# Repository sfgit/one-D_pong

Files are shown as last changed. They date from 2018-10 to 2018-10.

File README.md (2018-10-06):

# One D Pong
One dimensional pong board &amp; source code (made using Autodesk EAGLE 9.2)

This handheld version of One D pong was inspired by One D pong that a friend built for a Hackaday event ages ago.  The source code here (new) supports both one-player and two-player versions.  The files were designed in EAGLE.  To get the firmware programmed:

1)  Plug in your OTS Arduino Uno and setup as a programmer by loading the Arduino as ISP project and programming it.
2)  Next up, install a library to support programming ATMEGA 328P (there are MANY)...A few I use are:
    - https://github.com/leomil72/megax8
    - https://forum.arduino.cc/index.php?topic=412070
    
    FWIW, that second option is magical.  It uses Optiboot and is super user-friendly.  Follow the instructions on their    website and you can't go wrong.

3) Once you have that package installed, you can select the ATMEGA328 as the target and connect the Arduino's SPI (ISP) connections to the board's right-angle programming header...The pins are called out in the silkscreen on the board.
4) You'll first need to load the Arduino bootloader and you do this from the Arduino IDE using Tools->Burn Bootloader
5) With the bootloader flashed, you can then program any arduino sketch onto the board though since this is purpose-built for One-D pong, I would of course suggest using the One-D pong .ino file in this repo.

A few things to note:

- The LED driver ICs can sink more than they source.  They can only source about 10mA but they can sink something like 25mA.  This is why the LED cathodes are wired into those driver ICs and not to GND.  
- These boards were designed to be hand assembled and since I'm profoundly lazy, I chose to use Resistor Arrays and not individual resistors.  These little devices are small but they can definitely be hand soldered, probably far more easily than the TSSOP packages that the LED drivers use.  
- I made my own stencils using Kapton using the Glowforge Pro.  You can cut 5mil Dupont Kapton (non-adhesive) which you can get from Amazon using the following settings:
  - Speed: 650
  - Power: 90%
  - Passes: 3
  - Lines Per Inch: 225
  - Focus Height: 0.005in.

  This worked like a charm but took some cleanup afterwards.  The benefit of a stencil is of course repeatability.  If you have difficulty cutting Kapton, buy Mylar in 4mil sheets (again, Amazon) and cut that. 4mil Mylar will also take several passes to cut thru but I used settings very similar to the Kapton and that worked good.

Working version:

(http://www.youtube.com/watch?v=VkyKWFC-Sd0 "One Dimensional Pong")

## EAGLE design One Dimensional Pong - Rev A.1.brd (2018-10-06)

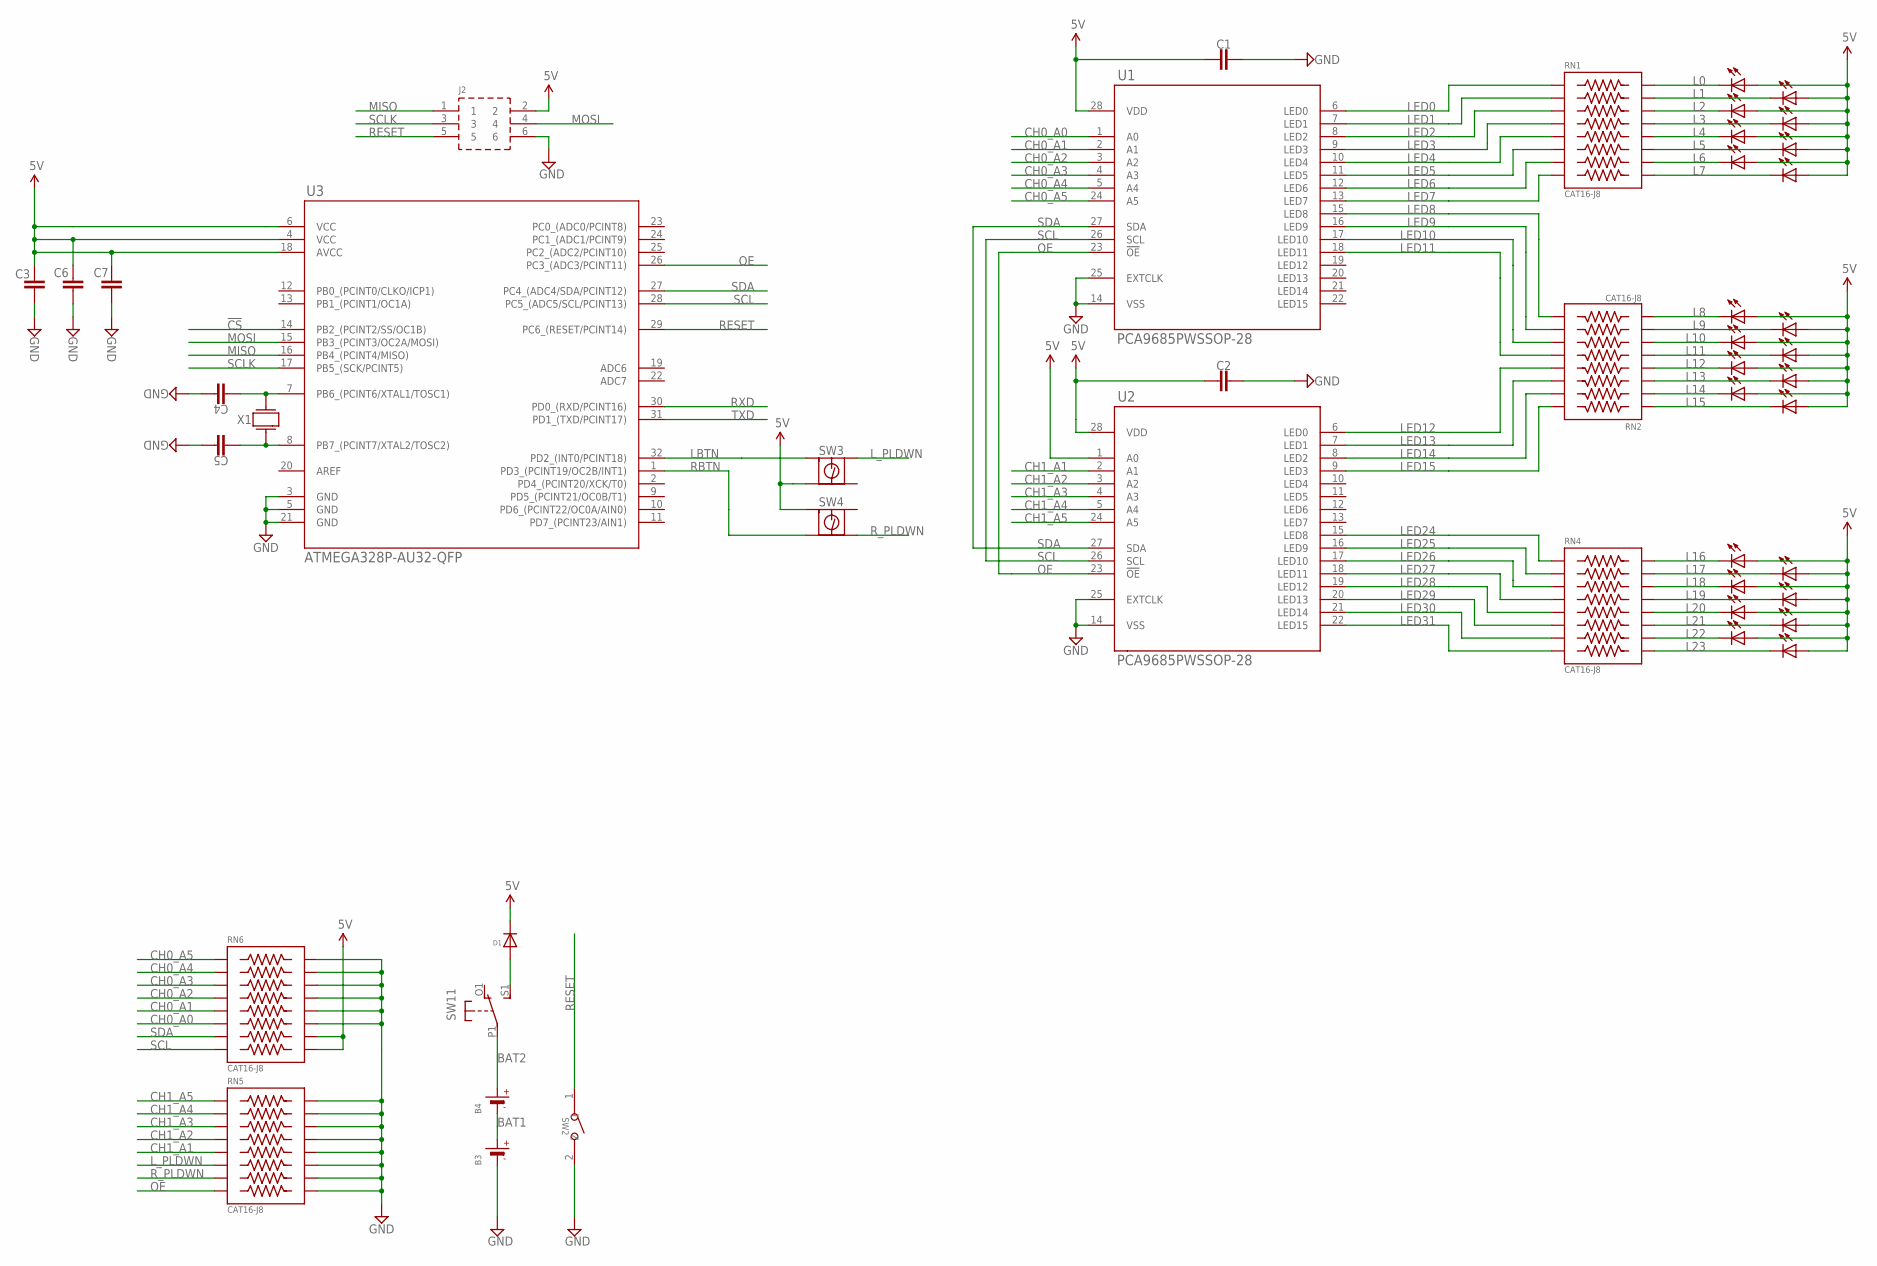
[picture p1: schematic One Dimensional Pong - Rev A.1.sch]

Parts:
B3, B4: BATTERYCR2540-SMT; CR2450
C1, C2, C3, C4, C5, C6, C7: C-EUC0805; C0805
D1: 1N4150W; SOD-123
J2: 610106249121; RA-SMT-HDR-2X3
LED1, LED5, LED28, LED32: LED0805-YELLOW; CHIP-LED0805-YELLOW
LED2, LED4, LED29, LED31: LED0805-ORANGE; CHIP-LED0805-ORANGE
LED3, LED30: LEDCHIPLED_0805; CHIPLED_0805
LED6, LED7, LED8, LED9, LED10, LED11, LED12, LED13, LED14, LED15, LED16, LED25, LED26, LED27: LED0805-GREEN; CHIP-LED0805-GREEN
RN1, RN2, RN4, RN5, RN6: CAT16-J8; RN8
SW1: DPDT-EG1390; EG1390
SW2: B3U-1000P-2P-SMD; SW2-2.6-3.0X2.5X1.2+0.4MM
SW3, SW4: PTS645SM43SMTR92LFS; PTS645-SMT-6MM
U1, U2: PCA9685PWSSOP-28; SOP65P640X110-28
U3: ATMEGA328P-AU32-QFP; QFP80P897X897X120-32
X1: ABLS-16.000MHZ-B4-T; OSC12P7X4P7

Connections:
5V: C1.1, C2.1, C3.1, C6.1, C7.1, D1.K (C), J2.2, LED1.A, LED2.A, LED3.A, LED4.A, LED5.A, LED6.A, LED7.A, LED8.A, LED9.A, LED10.A, LED11.A, LED12.A, LED13.A, LED14.A, LED15.A, LED16.A, LED25.A, LED26.A, LED27.A, LED28.A, LED29.A, LED30.A, LED31.A, LED32.A, RN6.14, RN6.16, SW3.P$3 (3), SW4.P$1 (1), U1.28 (VDD), U2.1 (A0), U2.28 (VDD), U3.4 (VCC), U3.6 (VCC), U3.18 (AVCC)
!CS: U3.14 (PB2_(PCINT2/SS/OC1B))
BAT1: B3.1 (+), B3.2 (+), B4.GND (-)
BAT2: B4.1 (+), B4.2 (+), SW1.P1
CH0_A0: RN6.11, U1.1 (A0)
CH0_A1: RN6.9, U1.2 (A1)
CH0_A2: RN6.7, U1.3 (A2)
CH0_A3: RN6.5, U1.4 (A3)
CH0_A4: RN6.3, U1.5 (A4)
CH0_A5: RN6.1, U1.24 (A5)
CH1_A1: RN5.9, U2.2 (A1)
CH1_A2: RN5.7, U2.3 (A2)
CH1_A3: RN5.5, U2.4 (A3)
CH1_A4: RN5.3, U2.5 (A4)
CH1_A5: RN5.1, U2.24 (A5)
GND: B3.GND (-), C1.2, C2.2, C3.2, C4.2, C5.2, C6.2, C7.2, J2.6, RN5.2, RN5.4, RN5.6, RN5.8, RN5.10, RN5.12, RN5.14, RN5.16, RN6.2, RN6.4, RN6.6, RN6.8, RN6.10, RN6.12, SW2.2, U1.14 (VSS), U1.25 (EXTCLK), U2.14 (VSS), U2.25 (EXTCLK), U3.3 (GND), U3.5 (GND), U3.21 (GND)
L0: LED1.C, RN1.2
L1: LED2.C, RN1.4
L2: LED3.C, RN1.6
L3: LED4.C, RN1.8
L4: LED5.C, RN1.10
L5: LED6.C, RN1.12
L6: LED7.C, RN1.14
L7: LED8.C, RN1.16
L8: LED9.C, RN2.15
L9: LED10.C, RN2.13
L10: LED11.C, RN2.11
L11: LED12.C, RN2.9
L12: LED13.C, RN2.7
L13: LED14.C, RN2.5
L14: LED15.C, RN2.3
L15: LED16.C, RN2.1
L16: LED25.C, RN4.2
L17: LED26.C, RN4.4
L18: LED27.C, RN4.6
L19: LED28.C, RN4.8
L20: LED29.C, RN4.10
L21: LED30.C, RN4.12
L22: LED31.C, RN4.14
L23: LED32.C, RN4.16
LBTN: SW3.P$1 (1), U3.32 (PD2_(INT0/PCINT18))
LED0: RN1.1, U1.6 (LED0)
LED1: RN1.3, U1.7 (LED1)
LED2: RN1.5, U1.8 (LED2)
LED3: RN1.7, U1.9 (LED3)
LED4: RN1.9, U1.10 (LED4)
LED5: RN1.11, U1.11 (LED5)
LED6: RN1.13, U1.12 (LED6)
LED7: RN1.15, U1.13 (LED7)
LED8: RN2.16, U1.15 (LED8)
LED9: RN2.14, U1.16 (LED9)
LED10: RN2.12, U1.17 (LED10)
LED11: RN2.10, U1.18 (LED11)
LED12: RN2.8, U2.6 (LED0)
LED13: RN2.6, U2.7 (LED1)
LED14: RN2.4, U2.8 (LED2)
LED15: RN2.2, U2.9 (LED3)
LED24: RN4.1, U2.15 (LED8)
LED25: RN4.3, U2.16 (LED9)
LED26: RN4.5, U2.17 (LED10)
LED27: RN4.7, U2.18 (LED11)
LED28: RN4.9, U2.19 (LED12)
LED29: RN4.11, U2.20 (LED13)
LED30: RN4.13, U2.21 (LED14)
LED31: RN4.15, U2.22 (LED15)
L_PLDWN: RN5.11, SW3.P$2 (2)
MISO: J2.1, U3.16 (PB4_(PCINT4/MISO))
MOSI: J2.4, U3.15 (PB3_(PCINT3/OC2A/MOSI))
unnamed: C4.1, U3.7 (PB6_(PCINT6/XTAL1/TOSC1)), X1.2
unnamed: C5.1, U3.8 (PB7_(PCINT7/XTAL2/TOSC2)), X1.1
unnamed: D1.A, SW1.S1 (S)
OE: RN5.15, U1.23 (!OE), U2.23 (!OE), U3.26 (PC3_(ADC3/PCINT11))
RBTN: SW4.P$3 (3), U3.1 (PD3_(PCINT19/OC2B/INT1))
RESET: J2.5, SW2.1, U3.29 (PC6_(RESET/PCINT14))
RXD: U3.30 (PD0_(RXD/PCINT16))
R_PLDWN: RN5.13, SW4.P$4 (4)
SCL: RN6.15, U1.26 (SCL), U2.26 (SCL), U3.28 (PC5_(ADC5/SCL/PCINT13))
SCLK: J2.3, U3.17 (PB5_(SCK/PCINT5))
SDA: RN6.13, U1.27 (SDA), U2.27 (SDA), U3.27 (PC4_(ADC4/SDA/PCINT12))
TXD: U3.31 (PD1_(TXD/PCINT17))

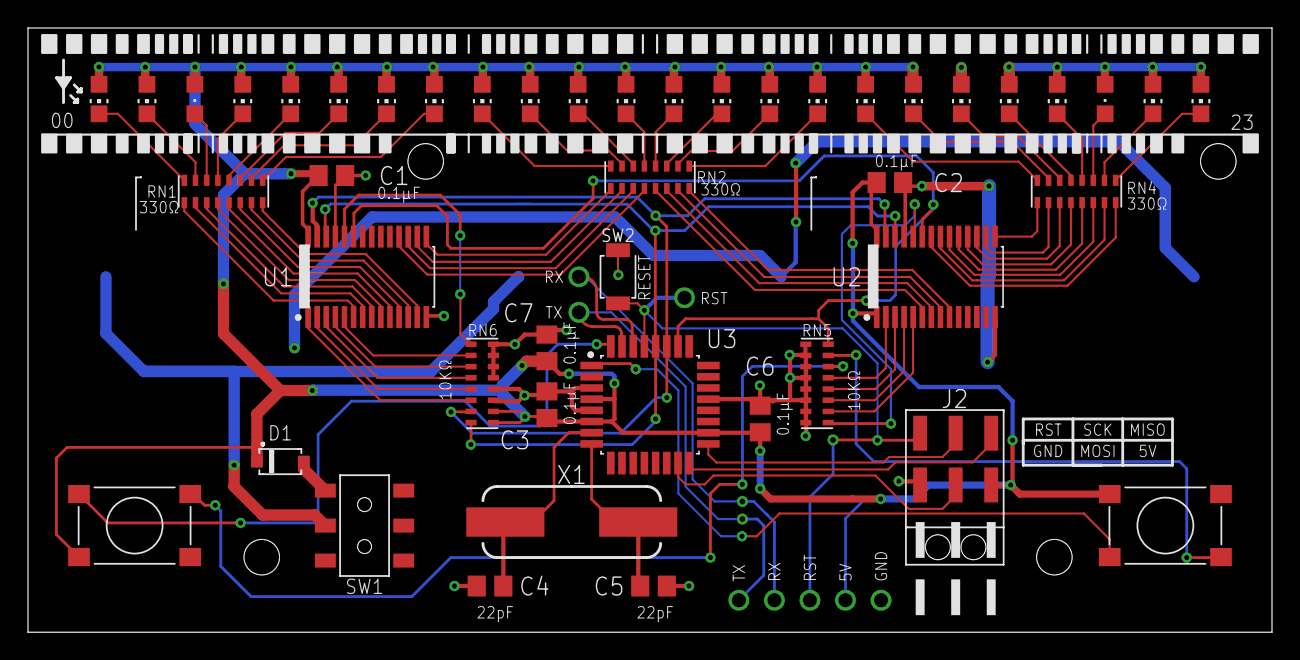
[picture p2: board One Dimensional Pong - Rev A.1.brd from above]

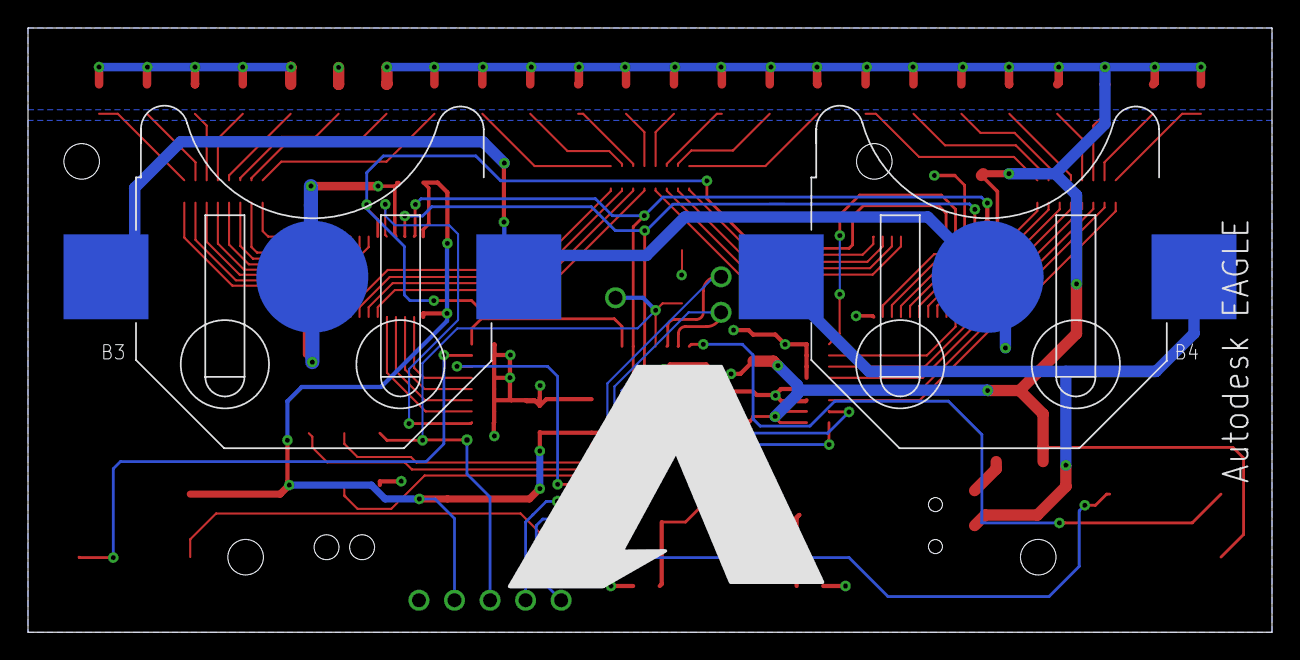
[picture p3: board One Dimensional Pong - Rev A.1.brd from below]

Board: 2 copper layers, 88.9 x 43.2 mm, 48 parts (2 on the bottom side), 77 nets.

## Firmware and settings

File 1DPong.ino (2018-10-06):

#include <Wire.h>
#include <Adafruit_PWMServoDriver.h>

#define PIN_BUTTON_LEFT 2
#define PIN_BUTTON_RIGHT 3
#define PIN_LED_ENABLE_N A3

#define LED_COUNT 24

#define LED_OFF 0xFF
#define LED_DIM 0x7F
#define LED_ON  0

class LedDisplay {
public:
  LedDisplay(unsigned char size);
  ~LedDisplay();

  unsigned char size(void) const { return mSize; };
  void setLed(unsigned char index, unsigned char value);
  void clear(void);
  void show(void);
private:
  Adafruit_PWMServoDriver mPwmDriver0;
  Adafruit_PWMServoDriver mPwmDriver1;
  unsigned char* mpLed;
  unsigned char mSize;
};

LedDisplay::LedDisplay(unsigned char size)
: mPwmDriver0(0x40)
, mPwmDriver1(0x41)
{
  mSize = size;
  mpLed = new unsigned char[size];
  clear();

  //
  pinMode(PIN_LED_ENABLE_N, OUTPUT);
  digitalWrite(PIN_LED_ENABLE_N, HIGH);

  // Setup PWM drivers
  mPwmDriver0.begin();
  mPwmDriver1.begin();
  mPwmDriver0.setPWMFreq(1600);  // This is the maximum PWM frequency
  mPwmDriver1.setPWMFreq(1600);  // This is the maximum PWM frequency
 
  // save I2C bitrate
  uint8_t twbrbackup = TWBR;
  // must be changed after calling Wire.begin() (inside pwm.begin())
  TWBR = 12; // upgrade to 400KHz!
}

LedDisplay::~LedDisplay() {
  delete [] mpLed;
}

void LedDisplay::setLed(unsigned char index, unsigned char value) {
  if (index < mSize) {
    mpLed[index] = value;
  }
}

void LedDisplay::clear(void) {
  for (unsigned char i = 0; i < mSize; ++i) {
    mpLed[i] = LED_OFF;
  }
}

void LedDisplay::show(void) {
  for (unsigned char i = 0; i < mSize; ++i) {
    unsigned short value = mpLed[i];
    value <<= 4;
    // Extend the LSB
    if (value & 0x0010) {
      value |= 0x000f;
    }
    if (i < 12) {
      mPwmDriver0.setPWM(i, 0, value);
    } else if (i < 16) {
      mPwmDriver1.setPWM(i - 12, 0, value);
    } else if (i < 24) {
      mPwmDriver1.setPWM(i - 8, 0, value);      
    }
  }
  digitalWrite(PIN_LED_ENABLE_N, LOW);
}

#define GAME_MODE_POWERON 0
#define GAME_MODE_SELECT_GAME 1
#define GAME_MODE_ONE_PLAYER 2
#define GAME_MODE_TWO_PLAYER 3
#define GAME_MODE_PLAYER_LOSE 4
#define GAME_MODE_PLAYER_WIN 5
#define GAME_MODE_PLAYER_LEFT_WIN 6
#define GAME_MODE_PLAYER_RIGHT_WIN 7

#define GAME_FRAME_MS_MAX 20
#define GAME_FRAME_MS_MIN 10
#define GAME_FRAME_MS_START 20
#define GAME_FRAME_MS_STEP 1

#define GAME_BALL_DIRECTION_LEFT 1   // Ball moving to the left
#define GAME_BALL_DIRECTION_RIGHT 2  // Ball moving to the right
#define GAME_BALL_DIRECTION_ANY 3    // Ball moving either way

#define GAME_BALL_POSITION_LEFT 0
#define GAME_BALL_POSITION_RIGHT 23
#define GAME_WIN_LEFT_LED_MIN 2
#define GAME_WIN_LEFT_LED_MAX 11
#define GAME_WIN_RIGHT_LED_MIN 12
#define GAME_WIN_RIGHT_LED_MAX 21

#define GAME_LEFT_PADDLE_POSITION 2
#define GAME_LEFT_HIT_POSITION_MIN 2
#define GAME_LEFT_HIT_POSITION_MAX 4
#define GAME_LEFT_HIT_DIRECTION GAME_BALL_DIRECTION_LEFT
#define GAME_LEFT_HIT_RESET_POSITION 21
#define GAME_LEFT_HIT_RESET_DIRECTION GAME_DIRECTION_LEFT

#define GAME_RIGHT_PADDLE_POSITION 21
#define GAME_RIGHT_HIT_POSITION_MIN 19
#define GAME_RIGHT_HIT_POSITION_MAX 21
#define GAME_RIGHT_HIT_DIRECTION GAME_BALL_DIRECTION_RIGHT
#define GAME_RIGHT_HIT_RESET_POSITION 21
#define GAME_RIGHT_HIT_RESET_DIRECTION GAME_DIRECTION_RIGHT

#define GAME_PRESS_ENABLE 0
#define GAME_PRESS_PRESSED 1

#define GAME_ONE_PLAYER_LOSE_SCORE 0
#define GAME_ONE_PLAYER_WIN_SCORE 9
#define GAME_TWO_PLAYER_WIN_SCORE 9

class Game {
public:
  Game();
  void setMode(unsigned char mode);
  void frame(void);
protected:
  void powerOnFrame(void);
  void selectGameFrame(void);
  void onePlayerFrame(void);
  void twoPlayerFrame(void);
  void playerLoseFrame(void);
  void playerWinFrame(void);
  void playerLeftWinFrame(void);
  void playerRightWinFrame(void);
  void gameFrame(void);
  
  bool checkLeftButton(bool enable = true);
  bool checkRightButton(bool enable = true);
  void displayScores(void);
  void handleBallAtLeftPaddle(void);
  void handleBallAtRightPaddle(void);
  void handleBallAtLeftEnd(void);
  void handleBallAtRightEnd(void);
  
  void speedUp(void);
  void slowDown(void);
private:
  LedDisplay mDisplay;
  unsigned char mMode;
  int mFrameMilliseconds;
  unsigned char mBallPosition;
  unsigned char mBallDirection;
  unsigned char mLeftPress;
  unsigned char mRightPress;
  unsigned char mLeftScore;
  unsigned char mRightScore;
};

Game::Game()
  : mDisplay(LED_COUNT)
{
  setMode(GAME_MODE_POWERON);
}

void Game::setMode(unsigned char mode) {
  mMode = mode;
  mFrameMilliseconds = GAME_FRAME_MS_START;
  mBallPosition = (mode == GAME_MODE_TWO_PLAYER)
    ? GAME_RIGHT_PADDLE_POSITION
    : GAME_LEFT_PADDLE_POSITION;
  mBallDirection = (mode == GAME_MODE_TWO_PLAYER)
    ? GAME_BALL_DIRECTION_LEFT
    : GAME_BALL_DIRECTION_RIGHT;
  mLeftPress = (mode == GAME_MODE_TWO_PLAYER)
    ? GAME_PRESS_ENABLE
    : GAME_PRESS_PRESSED;
  mRightPress = (mode == GAME_MODE_ONE_PLAYER)
    ? GAME_PRESS_ENABLE
    : GAME_PRESS_PRESSED;
  mLeftScore = (mode == GAME_MODE_ONE_PLAYER) ? 3 : 0;
  mRightScore = 0;
}

void Game::frame(void) {
  mDisplay.clear();
  displayScores();

  switch (mMode) {
  case GAME_MODE_POWERON:
    powerOnFrame();
    break;
  case GAME_MODE_SELECT_GAME:
    selectGameFrame();
    break;
  case GAME_MODE_ONE_PLAYER:
    onePlayerFrame();
    break;
  case GAME_MODE_TWO_PLAYER:
    twoPlayerFrame();
    break;
  case GAME_MODE_PLAYER_LOSE:
    playerLoseFrame();
    break;
  case GAME_MODE_PLAYER_WIN:
    playerWinFrame();
    break;
  case GAME_MODE_PLAYER_LEFT_WIN:
    playerLeftWinFrame();
    break;
  case GAME_MODE_PLAYER_RIGHT_WIN:
    playerRightWinFrame();
    break;
  default:
    setMode(GAME_MODE_POWERON);
  }

  mDisplay.show();
  delay(mFrameMilliseconds);
}

void Game::powerOnFrame(void) {
  if (mBallPosition <= GAME_BALL_POSITION_RIGHT) {
  mDisplay.setLed(mBallPosition, LED_ON);
    mDisplay.setLed(GAME_BALL_POSITION_RIGHT - mBallPosition, LED_ON);
  } else {
    setMode(GAME_MODE_SELECT_GAME);
  }
  if (++mBallPosition > GAME_BALL_POSITION_RIGHT + 16) {
    mBallPosition = GAME_BALL_POSITION_RIGHT + 1;
  }
}

void Game::selectGameFrame(void) {
  if (mBallPosition < 8) {
      mDisplay.setLed(0, LED_ON);    
  } else {
      mDisplay.setLed(23, LED_ON);
      mDisplay.setLed(19, LED_ON);    
  }
  if (++mBallPosition >= 16) {
    mBallPosition = 0;
  }
  if (checkLeftButton()) {
    setMode(GAME_MODE_ONE_PLAYER);
  } else if (checkRightButton()) {
    setMode(GAME_MODE_TWO_PLAYER);
  }
}

void Game::onePlayerFrame(void) {
  gameFrame();
}

void Game::twoPlayerFrame(void) {
  gameFrame();
}

void Game::gameFrame(void) {
  // Display the paddles
  mDisplay.setLed(GAME_LEFT_PADDLE_POSITION, LED_DIM);
  mDisplay.setLed(GAME_RIGHT_PADDLE_POSITION, LED_DIM);

  // Display the ball at the current location
  mDisplay.setLed(mBallPosition, LED_ON);
  
  // Handle events
  if (mBallPosition >= GAME_LEFT_HIT_POSITION_MIN
    && mBallPosition <= GAME_LEFT_HIT_POSITION_MAX
    && mBallDirection == GAME_LEFT_HIT_DIRECTION) {      
    handleBallAtLeftPaddle();
  } else if (mBallPosition >= GAME_RIGHT_HIT_POSITION_MIN
    && mBallPosition <= GAME_RIGHT_HIT_POSITION_MAX
    && mBallDirection == GAME_RIGHT_HIT_DIRECTION) {
    handleBallAtRightPaddle();
  } else if (mBallPosition == GAME_BALL_POSITION_LEFT
     && mBallDirection == GAME_LEFT_HIT_DIRECTION) {
    handleBallAtLeftEnd();
    mBallDirection = GAME_BALL_DIRECTION_RIGHT;
  } else if (mBallPosition == GAME_BALL_POSITION_RIGHT
    && mBallDirection == GAME_RIGHT_HIT_DIRECTION) {
    handleBallAtRightEnd();
    mBallDirection = GAME_BALL_DIRECTION_LEFT;
  } else {
    checkLeftButton(false);
    checkRightButton(false);
  }
  
  // Advance the ball
  if (mBallDirection == GAME_BALL_DIRECTION_RIGHT) {
    ++mBallPosition;
  } else {
    --mBallPosition;
  }
}

void Game::playerLoseFrame(void) {
  mDisplay.setLed(GAME_LEFT_PADDLE_POSITION, LED_ON);
  mDisplay.setLed(GAME_RIGHT_PADDLE_POSITION, LED_ON);
  if (mBallPosition & 0x3) {
    mDisplay.setLed(GAME_LEFT_PADDLE_POSITION - 1, LED_ON);
    mDisplay.setLed(GAME_LEFT_PADDLE_POSITION + 1, LED_ON);
    mDisplay.setLed(GAME_RIGHT_PADDLE_POSITION - 1, LED_ON);
    mDisplay.setLed(GAME_RIGHT_PADDLE_POSITION + 1, LED_ON);
  }
  if (mBallPosition & 0x2 == 0x2) {
    mDisplay.setLed(GAME_LEFT_PADDLE_POSITION - 2, LED_ON);
    mDisplay.setLed(GAME_LEFT_PADDLE_POSITION + 2, LED_ON);
    mDisplay.setLed(GAME_RIGHT_PADDLE_POSITION - 2, LED_ON);
    mDisplay.setLed(GAME_RIGHT_PADDLE_POSITION + 2, LED_ON);
  }
  if (checkLeftButton() || checkRightButton()) {
    setMode(GAME_MODE_SELECT_GAME);
  }
  ++mBallPosition;
  mBallPosition &= 0x3;
}

void Game::playerWinFrame(void) {
  for (unsigned int i = 0; i < mBallPosition; ++i) {
    mDisplay.setLed(GAME_WIN_LEFT_LED_MAX - i, LED_ON);
    mDisplay.setLed(GAME_WIN_RIGHT_LED_MIN + i, LED_ON);
  }
  if (checkLeftButton() || checkRightButton()) {
    setMode(GAME_MODE_SELECT_GAME);
  }
  if (++mBallPosition > GAME_WIN_LEFT_LED_MAX - GAME_WIN_LEFT_LED_MIN) {
    mBallPosition = 0;
  }
}

void Game::playerLeftWinFrame(void) {
  for (unsigned int i = 0; i < mBallPosition; ++i) {
    mDisplay.setLed(GAME_WIN_LEFT_LED_MAX - i, LED_ON);
  }
  if (checkLeftButton() || checkRightButton()) {
    setMode(GAME_MODE_SELECT_GAME);
  }
  if (++mBallPosition > GAME_WIN_LEFT_LED_MAX - GAME_WIN_LEFT_LED_MIN) {
    mBallPosition = 0;
  }
}

void Game::playerRightWinFrame(void) {
  for (unsigned int i = 0; i < mBallPosition; ++i) {
    mDisplay.setLed(GAME_WIN_RIGHT_LED_MIN + i, LED_ON);
  }
  if (checkLeftButton() || checkRightButton()) {
    setMode(GAME_MODE_SELECT_GAME);
  }
  if (++mBallPosition > GAME_WIN_RIGHT_LED_MAX - GAME_WIN_RIGHT_LED_MIN) {
    mBallPosition = 0;
  }
}

void Game::handleBallAtLeftPaddle(void) {
  // Reenable the right button
  mRightPress = GAME_PRESS_ENABLE;
  if (checkLeftButton(false)) {
    // Left button hit at the proper time
    if (mMode == GAME_MODE_ONE_PLAYER) {
      if (++mLeftScore == GAME_ONE_PLAYER_WIN_SCORE) {
        setMode(GAME_MODE_PLAYER_WIN);
      }
    }
    mBallDirection = GAME_BALL_DIRECTION_RIGHT;
    speedUp();
  }
}

void Game::handleBallAtRightPaddle(void) {
  // Reenable the right button
  mLeftPress = GAME_PRESS_ENABLE;
  if (checkRightButton(false)) {
    // Right button hit at the proper time
    if (mMode == GAME_MODE_ONE_PLAYER) {
      if (++mLeftScore == GAME_ONE_PLAYER_WIN_SCORE) {
        setMode(GAME_MODE_PLAYER_WIN);
      }
    }
    mBallDirection = GAME_BALL_DIRECTION_LEFT;
    speedUp();
  }
}

void Game::handleBallAtLeftEnd(void) {
  // Reenable the right button
  mRightPress = GAME_PRESS_ENABLE;
  if (mMode == GAME_MODE_ONE_PLAYER) {
    // Reduce the score by one
    if (--mLeftScore == GAME_ONE_PLAYER_LOSE_SCORE) {
      setMode(GAME_MODE_PLAYER_LOSE);
    }
  } else if (mMode == GAME_MODE_TWO_PLAYER) {
    // Increase the right player's score
    if (++mRightScore == GAME_TWO_PLAYER_WIN_SCORE) {
      setMode(GAME_MODE_PLAYER_RIGHT_WIN);
    }
  }
  slowDown();
}

void Game::handleBallAtRightEnd(void) {
  // Reenable the right button
  mLeftPress = GAME_PRESS_ENABLE;
  if (mMode == GAME_MODE_ONE_PLAYER) {
    // Reduce the score by one
    if (--mLeftScore == GAME_ONE_PLAYER_LOSE_SCORE) {
      setMode(GAME_MODE_PLAYER_LOSE);
    }
  } else if (mMode == GAME_MODE_TWO_PLAYER) {
    // Increase the left player's score
    if (++mLeftScore == GAME_TWO_PLAYER_WIN_SCORE) {
      setMode(GAME_MODE_PLAYER_LEFT_WIN);
    }
  }
  slowDown();
}

void Game::speedUp(void) {
  mFrameMilliseconds -= GAME_FRAME_MS_STEP;
  if (mFrameMilliseconds < GAME_FRAME_MS_MIN) {
    mFrameMilliseconds = GAME_FRAME_MS_MIN;
  }
}

void Game::slowDown(void) {
  mFrameMilliseconds += GAME_FRAME_MS_STEP;
  if (mFrameMilliseconds > GAME_FRAME_MS_MAX) {
    mFrameMilliseconds = GAME_FRAME_MS_MAX;
  }
}

bool Game::checkLeftButton(bool enable) {
  if (mLeftPress == GAME_PRESS_PRESSED) {
    if (enable && digitalRead(PIN_BUTTON_LEFT) == LOW) {
      mLeftPress = GAME_PRESS_ENABLE;
    }
    return false;
  } else if (enable) {
    mLeftPress = GAME_PRESS_ENABLE;
  }
  if (mLeftPress == GAME_PRESS_ENABLE) {
    if (digitalRead(PIN_BUTTON_LEFT) == HIGH) {
      mLeftPress = GAME_PRESS_PRESSED;
      return true;
    }
  }
  return false;
}

bool Game::checkRightButton(bool enable) {
  if (mRightPress == GAME_PRESS_PRESSED) {
    if (enable && digitalRead(PIN_BUTTON_RIGHT) == LOW) {
      mRightPress = GAME_PRESS_ENABLE;
    }
    return false;
  } else if (enable) {
    mRightPress = GAME_PRESS_ENABLE;
  }
  if (mRightPress == GAME_PRESS_ENABLE) {
    if (digitalRead(PIN_BUTTON_RIGHT) == HIGH) {
      mRightPress = GAME_PRESS_PRESSED;
      return true;
    }
  }
  return false;
}

void Game::displayScores(void) {
  unsigned int i;
  for (i = 0; i < mLeftScore; ++i) {
    mDisplay.setLed(3 + i, LED_DIM);
  }
  for (i = 0; i < mRightScore; ++i) {
    mDisplay.setLed(20 - i, LED_DIM);
  }
}

//----------------------------------------------
void setup()
{
  pinMode(PIN_BUTTON_LEFT, INPUT);
  digitalWrite(PIN_BUTTON_LEFT, LOW);
  pinMode(PIN_BUTTON_RIGHT, INPUT);
  digitalWrite(PIN_BUTTON_RIGHT, LOW);
}

void loop()
{
  static Game game;
  
  game.frame(); 
}
